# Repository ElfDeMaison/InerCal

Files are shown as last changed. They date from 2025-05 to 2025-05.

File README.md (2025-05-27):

# InerCal – Système de calcul du moment d'inertie embarqué

**InerCal** est un système embarqué destiné à mesurer le **moment d'inertie d'un objet** à l'aide d'un **balancier à deux fils**. Il s’appuie sur une carte **ESP32** et embarque une interface web accessible en Wi-Fi. Le système permet de récupérer les données de mesure directement via un navigateur web sans besoin de logiciel externe.

---

## Objectif

Le but du projet est de fournir un outil **simple, autonome et portable** pour estimer le moment d'inertie d'objets à partir des oscillations d’un système pendulaire.

Le système :

- enregistre les oscillations via un capteur (type ICM-42688),
- envoie les données sur un serveur web embarqué dans l’ESP32,
- affiche les mesures sur une **interface web responsive**.

---

## Matériel requis

- 1x **ESP32** (WROOM ou équivalent)
- 1x **Capteur inertiel** (ex. ICM-42688 via SPI ou I2C)

---

## Guide d'utilisation 

Voici les étapes à suivre pour utiliser le système **InerCal** avec un objet réel :

### Installation physique

1. **Fixer l’InerCal** solidement sur l’objet dont vous souhaitez mesurer le moment d'inertie.

2. **Allumer l’ESP32** (via USB ou batterie).

---

### Connexion et interface

3. **Se connecter au Wi-Fi** de l’ESP32 (point d’accès créé automatiquement).

4. Ouvrir un navigateur et accéder à l’interface via l’adresse IP indiquée dans le moniteur série (ou adresse par défaut, souvent `192.168.4.1`).

---

### Mesure du moment d'inertie

5. **Calibrer le gyroscope** en cliquant sur le bouton **"Calibrer le gyroscope"**.

6. Cliquer sur **"Démarrer"** pour lancer la capture des données.

7. **Faire osciller l’objet** autour de son axe de rotation.

8. Une fois les oscillations terminées, cliquer sur **"Arrêter"**.

---

### Analyse des données

9. **Remplir les champs physiques** dans l’interface (masse, distance, etc.).

10. Cliquer sur **"Télécharger les données"** → un fichier `.json` est enregistré.

---

### Post-traitement avec Python

11. Lancer le script Python d’analyse :

```bash
python analyse.py

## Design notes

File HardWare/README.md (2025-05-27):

 # InerCal HardWare

microcontroleur = [XIAO-ESP32-C3 seeed studio](https://wiki.seeedstudio.com/XIAO_ESP32C3_Getting_Started/)

IMU = ICM42688-P

Library KiCad = https://github.com/MGRZ31/Kicad_Libraries_GRZ

TODO : Le signal MISO a ete deplacé du GPIO9 au GPIO20 car cela empêche l'esp32 de démarrer correctement

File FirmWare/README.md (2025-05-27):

# InerCal software

## Prérequis

- [PlatformIO](https://platformio.org/)
- Python 3

## Installation

# Cloner le dépôt
```bash
git clone https://github.com/votre-utilisateur/InerCal.git
cd InerCal
```

# Créer un environnement virtuel Python
```bash
python3 -m venv env
source env/bin/activate  # Sous Windows : env\Scripts\activate
pip install -r requirements.txt
```  
## Upload websever data

Run this command to upload the webserver data (html, JS, CSS...) to the ESP32:

`pio run --target uploadfs`

## Flash ESP32

`pio run --target upload`

## Buid Code 

`pio run`

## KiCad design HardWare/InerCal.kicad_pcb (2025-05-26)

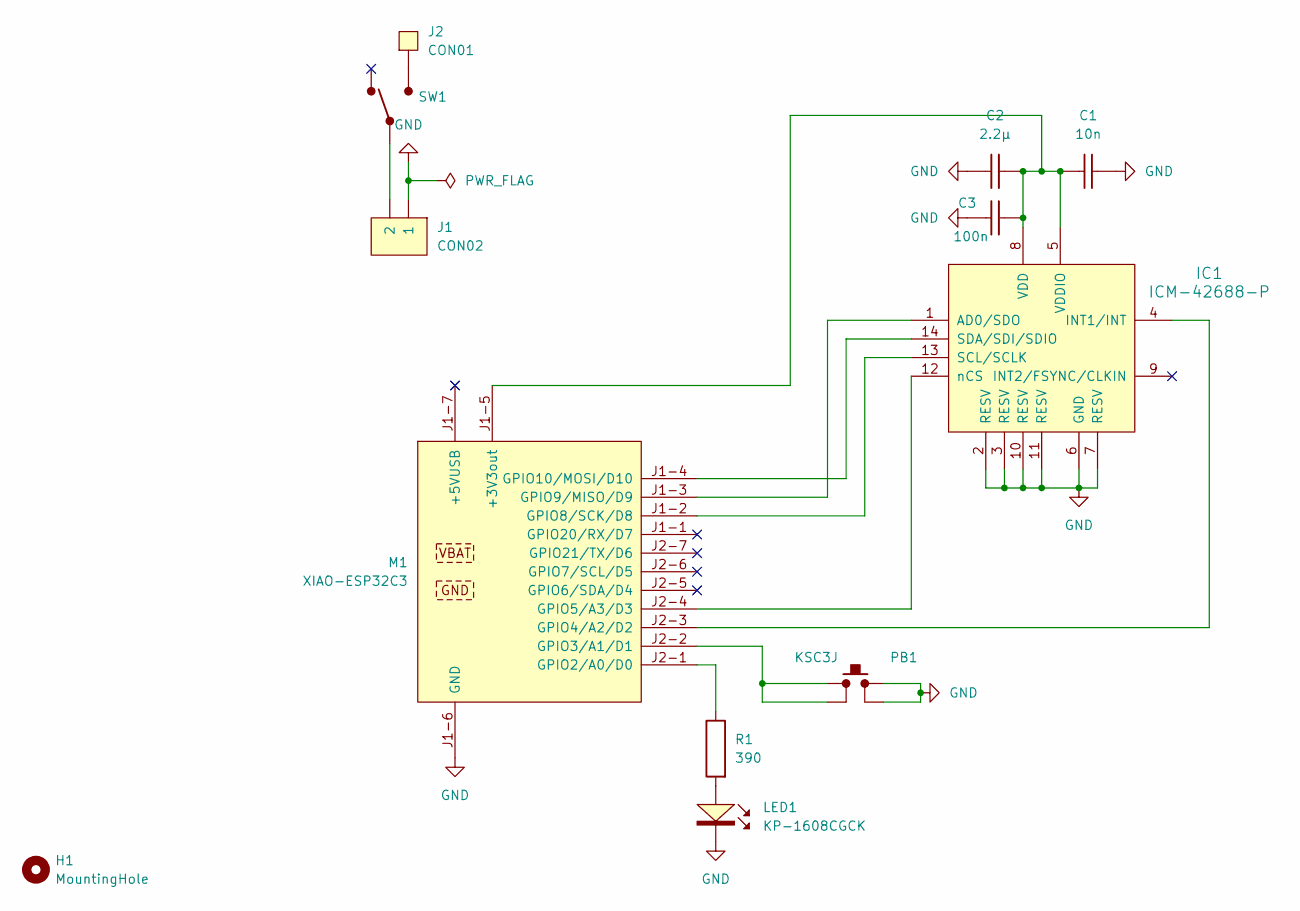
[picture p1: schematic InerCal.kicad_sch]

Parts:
C1: 10n; C_0603
C2: 2.2µ; C_0603
C3: 100n; C_0603
H1: MountingHole; MountingHole_2.2mm_M2
IC1: ICM-42688-P
J1: CON02; PicoBlade_53261-0271
J2: CON01; SquareWirePad_SMD_2x4mm
LED1: KP-1608CGCK
M1: XIAO-ESP32C3; XIAO-ESP32C3_Socket_SMD
PB1: KSC3J
R1: 390; R_0603
SW1: 1K2; 1K2_90deg

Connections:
GND: C1.2, C2.1, C3.1, IC1.2 (RESV), IC1.3 (RESV), IC1.6 (GND), IC1.7 (RESV), IC1.10 (RESV), IC1.11 (RESV), J1.1, LED1.1 (K), M1.J1-6 (GND), PB1.2, PB1.3
unnamed: IC1.1 (AD0/SDO), M1.J1-3 (GPIO9/MISO/D9)
unnamed: IC1.4 (INT1/INT), M1.J2-3 (GPIO4/A2/D2)
unnamed: IC1.13 (SCL/SCLK), M1.J1-2 (GPIO8/SCK/D8)
unnamed: IC1.14 (SDA/SDI/SDIO), M1.J1-4 (GPIO10/MOSI/D10)
unnamed: C1.1, C2.2, C3.2, IC1.5 (VDDIO), IC1.8 (VDD), M1.J1-5 (+3V3out)
unnamed: IC1.12 (nCS), M1.J2-4 (GPIO5/A3/D3)
unnamed: J1.2, SW1.1
unnamed: J2.1, SW1.3
unnamed: LED1.2 (A), R1.1
unnamed: M1.J2-1 (GPIO2/A0/D0), R1.2
unnamed: M1.J2-2 (GPIO3/A1/D1), PB1.1, PB1.4

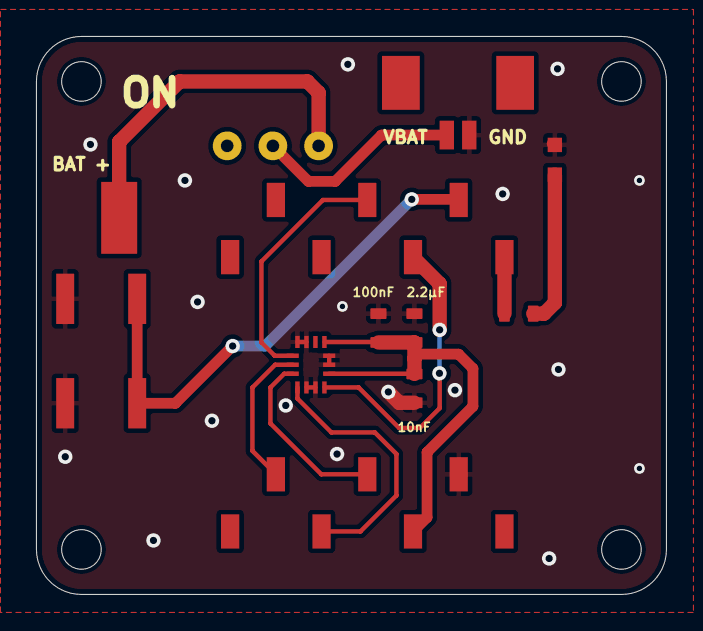
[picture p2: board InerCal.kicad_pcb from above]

Board: 2 copper layers, 35.0 x 31.0 mm, 15 parts (0 on the bottom side), 12 nets.

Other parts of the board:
H1#2, H1#3, H1#4: MountingHole; MountingHole_2.2mm_M2

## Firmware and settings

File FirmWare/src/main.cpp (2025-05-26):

#include <WiFi.h>
#include <Arduino.h>
#include <SPI.h>
#include "wifi_config.h"
#include "icm42688.h"
#include "server.h"
#include "freertos/FreeRTOS.h"

#define LED 2  // LED intégrée pour debug visuel

float previousAcc = 0;
float currentAcc = 0;

// Tâche de clignotement LED (utilisée pour confirmer que le système tourne)
void blinker(void*) {
  pinMode(LED, OUTPUT);
  while (true) {
    digitalWrite(LED, HIGH);
    vTaskDelay(pdMS_TO_TICKS(500));
    digitalWrite(LED, LOW);
    vTaskDelay(pdMS_TO_TICKS(500));
  }
}

// Fonction d'initialisation principale
void setup() {
  Serial.begin(115200);
  delay(5000);  // Pour laisser le temps d'ouvrir le moniteur série

  Serial.println("Boot ESP32...");

  // Tâche clignotante de debug
  xTaskCreate(blinker, "Blinker", 1024, NULL, 1, NULL);
  Serial.println("Tâche Blinker OK");

  // Création d'un point d'accès Wi-Fi local
  WiFi.softAP(ssid, password);
  Serial.println("Point d'accès Wi-Fi créé !");
  Serial.println("Adresse IP : " + WiFi.softAPIP().toString());

  // Initialisation du capteur ICM42688 via SPI
  Serial.println("Initialisation ICM...");
  setupICM();
  Serial.println("IMU OK");

  // Initialisation du serveur SPIFFS et WebSocket
  Serial.println("Setup Serveur...");
  setupServer();
  Serial.println("Serveur OK");

  // Tâches FreeRTOS : capteur, communication, Web
  xTaskCreatePinnedToCore(sensorValues, "SensorValues", 4096, NULL, 1, NULL, 1);
  xTaskCreatePinnedToCore(broadcastSensorData, "BroadcastData", 8192, NULL, 1, NULL, 0);
  xTaskCreatePinnedToCore(handleRoot, "HandleRoot", 4096, NULL, 1, NULL, 0);

  Serial.println("Setup terminé !");
}

void loop() {
  vTaskDelay(pdMS_TO_TICKS(100));  // Laisse le système tourner sans bloquer
}

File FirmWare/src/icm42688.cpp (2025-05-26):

// icm42688.cpp
#include "icm42688.h"

ICM42688 imu(SPI, 5);

// Offsets de calibration (accéléromètre et gyroscope)
float offsetX = 0, offsetY = 0, offsetZ = 0;
float offsetGyroX = 0, offsetGyroY = 0, offsetGyroZ = 0;

// Axe gravitationnel mesuré à la calibration
float g0x = 0, g0y = 0, g0z = 0;

// Variables partagées entre tâches (externes)
unsigned long lastTime = 0;
unsigned long currentTime = 0;
float ax, ay, az, gyrox, gyroy, gyroz;

// Estimation de l'angle (theta), sa vitesse et son accélération
float thetaHat = 0;
float thetaDotHat_t = 0;
float thetaDotHat_t_1 = 0;
float thetaDotDotHat_t = 0;

static volatile float latestTheta = 0;
static volatile float latestThetaDot = 0;
static volatile float latestThetaDotDot = 0;

// Initialisation SPI et du capteur ICM42688
void setupICM() {
    SPI.begin(8, 20, 10);  // SCK = GPIO8, MISO = GPIO20, MOSI = GPIO10
    Serial.println("Début initialisation ICM42688...");

    int status = imu.begin();
    if (status < 0) {
        Serial.println("Échec de la connexion au ICM42688 !");
        while (1);
    }
    Serial.println("ICM42688 connecté avec succès !");
}

// Affiche les valeurs brutes du capteur
void print_Acc_XYZ() {
    imu.getAGT();
    Serial.print("accX: "); Serial.print(imu.accX());
    Serial.print("\taccY: "); Serial.print(imu.accY());
    Serial.print("\taccZ: "); Serial.print(imu.accZ());
    Serial.print("\tgyrX: "); Serial.print(imu.gyrX());
    Serial.print("\tgyrY: "); Serial.print(imu.gyrY());
    Serial.print("\tgyrZ: "); Serial.print(imu.gyrZ());
    Serial.print("\ttemp: "); Serial.println(imu.temp());
}

// Tâche FreeRTOS : lecture des capteurs + calcul de l'angle
void sensorValues(void*) {
    while (true) {
            imu.getAGT();

            ax = imu.accX() - offsetX;
            ay = imu.accY() - offsetY;
            az = imu.accZ() - offsetZ;

            gyrox = imu.gyrX() - offsetGyroX;
            gyroy = imu.gyrY() - offsetGyroY;
            gyroz = imu.gyrZ() - offsetGyroZ;

            // Calcul des valeurs angulaires
            currentTime = millis();
            float dt = (currentTime - lastTime) / 1000.0f;

            thetaDotHat_t = gyroz;  // Choix de l'axe z ici (modifiable)
            thetaHat += thetaDotHat_t * dt;

            // Ramener theta entre -180° et +180°
            if (thetaHat > 180.0f)
            thetaHat -= 360.0f;
            else if (thetaHat < -180.0f)
            thetaHat += 360.0f;
            thetaHat = remainderf(thetaHat, 360.0f);  



            thetaDotDotHat_t = (thetaDotHat_t - thetaDotHat_t_1) / dt;
            thetaDotHat_t_1 = thetaDotHat_t;

            latestTheta = thetaHat;
            latestThetaDot = thetaDotHat_t;
            latestThetaDotDot = thetaDotDotHat_t;

            lastTime = currentTime;
            //print_Acc_XYZ();
        vTaskDelay(pdMS_TO_TICKS(5));  // Fréquence : 100 Hz
    }
}

// Calibration du gyroscope sur 1000 échantillons
void calibrateGyro() {
    float sumX = 0, sumY = 0, sumZ = 0;
    for (int i = 0; i < 1000; i++) {
        imu.getAGT();
        sumX += imu.gyrX();
        sumY += imu.gyrY();
        sumZ += imu.gyrZ();
        delay(2);
    }
    offsetGyroX = sumX / 1000.0;
    offsetGyroY = sumY / 1000.0;
    offsetGyroZ = sumZ / 1000.0;

    //  Remise à zéro des états angulaires
    thetaHat = 0;
    thetaDotHat_t = 0;
    thetaDotHat_t_1 = 0;
    thetaDotDotHat_t = 0;

    latestTheta = 0;
    latestThetaDot = 0;
    latestThetaDotDot = 0;

    Serial.println("Gyroscope calibré. État angulaire remis à zéro.");
}

// Calibration de l'accéléromètre avec retrait de la gravité
void calibrateAcc() {
    float sumX = 0, sumY = 0, sumZ = 0;
    for (int i = 0; i < 1000; i++) {
        imu.getAGT();
        sumX += imu.accX();
        sumY += imu.accY();
        sumZ += imu.accZ();
        delay(2);
    }
    offsetX = sumX / 1000.0;
    offsetY = sumY / 1000.0;
    offsetZ = sumZ / 1000.0 - 1.0;  // Suppression gravité (1g)

    g0x = offsetX;
    g0y = offsetY;
    g0z = offsetZ;
}

void getSensorData(SensorData *data)
{
    data->ax = ax;
    data->ay = ay;
    data->az = az;
    data->gyrox = gyrox;
    data->gyroy = gyroy;
    data->gyroz = gyroz;
    data->theta = latestTheta;
    data->thetaDot = latestThetaDot;
    data->thetaDotDot = latestThetaDotDot;
}
